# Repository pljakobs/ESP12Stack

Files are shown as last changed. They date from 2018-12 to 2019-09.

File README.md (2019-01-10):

# ESP12Stack
### An ESP12 Platform, adhering to the 30x30mm breakout boards often found but much more functional.
I have tested it with:
- ESPEasy
- SONOFF-TASMOTA
- Micropython
- Arduino
### Hardware
At this point, there is the base board which has:
- an ESP12 with all GPIO Pins brought to 2.54mm pin headers along the edge
- four WS2812B RGB or SK6812 RGBW individually addressable LEDs, which can be configured to be driven by various GPIO pins using 470Ohm resistors:
  - J02 -> GPIO2
  - J04 -> GPIO4
  - J05 -> GPIO5
  - J12 -> GPIO12
  - J13 -> GPIO13
only one of those should be installed at any given time
- low drop 3.3V regulator, the system can be powered either via the on-board USB connector or the 5V Vcc pin. Since there's no protection and those two 5V supplies form just one net, I suggest never to use both at the same time to avoid damage to your USB power source
- miniature switches for GPIO0 (FLASH) and RESET
- all necessary pull up / pull down resistors to be working as a stand alone device

In the FTDI vesion (currently untested) I have added an FTDI232 chip which should make the whole device in-place programmable, so no external USB-UART adapter is needed. Just plug it in to your PCs USB and you can talk to the ESP's UART
### There are a few other boards as well
- a 12-36V Switching Power Supply board that provides 5V (provided the feedback resistors are set correctly) to power the stack in an environment that requires those power levels (like a car)
- a five channel MOSFET board that can drive common anode LED strips
- an "experimentation" board that only has the VCC and GND pins pulled out to the outer row of mounting holes and otherwise offers as much of a "standard" layout board as possible for your own devices
### What I'm, working on:
the next board to come should be a display that just plugs on top of the base board, offering 240x240px through I2C

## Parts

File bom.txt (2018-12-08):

Partlist

Exported from esp12Stack.brd at 07.12.2018 13:59

EAGLE Version 7.7.0 Copyright (c) 1988-2016 CadSoft

Assembly variant: 

Part     Value             Package        Library       Position (inch)       Orientation

C1       100u              C0805          eagle-ltspice (0.45 0.4125)         MR270
C2       10u               C0805          eagle-ltspice (0.45 0.5875)         MR90
FLASH    SPST.B3U-3000P(M) B3U-3000P(M)   omron         (1 0.05)              MR180
GND      MCP1700SOT23      SOT-23         MCP1700       (0.6 0.45)            MR90
J02      470               R0805          eagle-ltspice (1.01875 0.525)       MR180
J04      470               R0805          eagle-ltspice (1.01875 0.61875)     MR180
J05      470               R0805          eagle-ltspice (1.01875 0.7125)      MR180
J12      470               R0805          eagle-ltspice (0.3 0.65)            MR270
J13      470               R0805          eagle-ltspice (0.3 0.4125)          MR270
JVCC     0R                R0805          eagle-ltspice (0.66875 0.51875)     MR180
LED1     WS2812B5050       WS2812B        adafruit      (1.1 1.05)            R180
LED2     WS2812B5050       WS2812B        adafruit      (0.15 1.05)           R180
LED3     WS2812B5050       WS2812B        adafruit      (0.2625 0.1125)       R0
LED4     WS2812B5050       WS2812B        adafruit      (0.975 0.1125)        R0
MDL1                       ESP8266-ESP12E ESP12E        (0.3 0.25)            R0
R1       10k               R0805          eagle-ltspice (0.5 0.85)            MR180
R2       10k               R0805          eagle-ltspice (0.5 0.75)            MR180
R3       10k               R0805          eagle-ltspice (0.66875 0.60625)     MR0
R4       10k               R0805          eagle-ltspice (0.66875 0.69375)     MR0
R5       10k               R0805          eagle-ltspice (0.75 0.35)           MR90
REST     SPST.B3U-3000P(M) B3U-3000P(M)   omron         (0.25 0.05)           MR180
SV1                        MA08-1         con-lstb      (0.0625 0.5)          R270
SV2                        MA08-1         con-lstb      (1.175 0.5)           R270
U$2      MICRO-USB         MICRO-USB      microusb (1)  (0.6 0)               MR0

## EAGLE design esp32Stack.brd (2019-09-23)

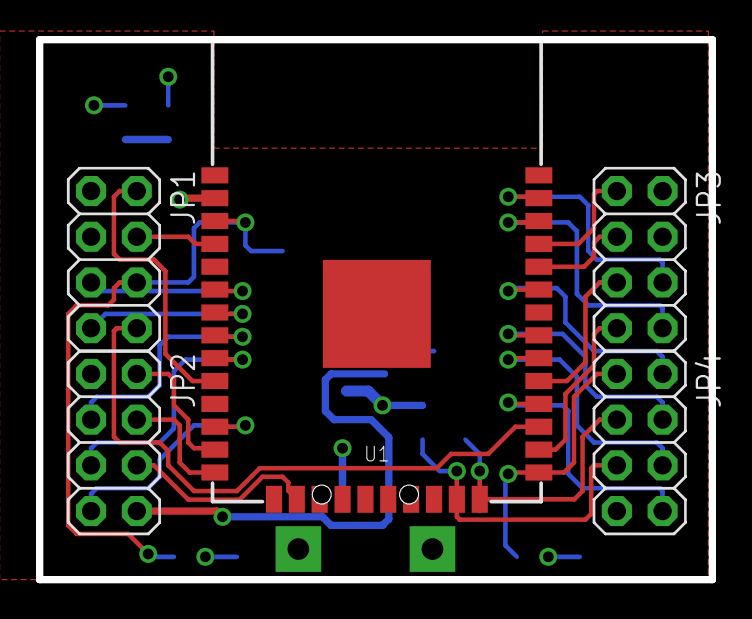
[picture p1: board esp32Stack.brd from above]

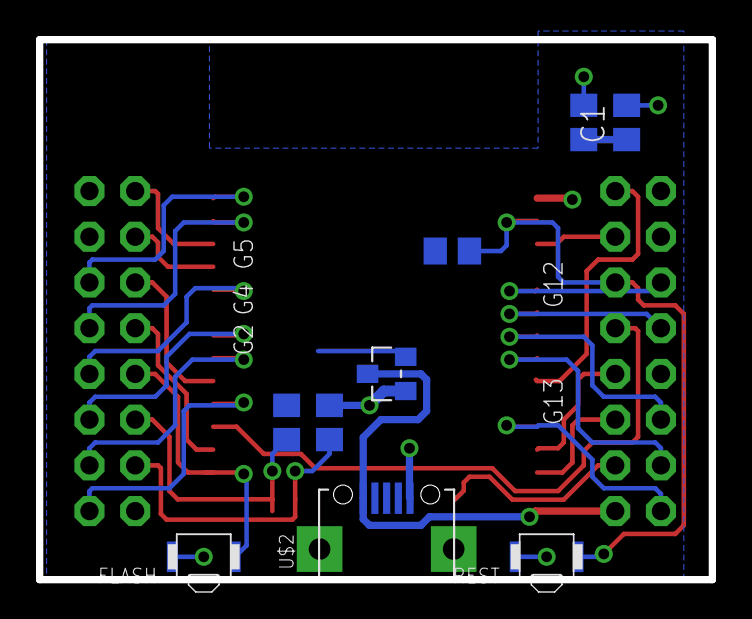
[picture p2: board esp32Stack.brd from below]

Board: 2 copper layers, 37.4 x 30.0 mm, 14 parts (9 on the bottom side), 28 nets.

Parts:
C1: 100u; C0805
C2: 10u; C0805
FLASH: SPST.B3U-3000P(M); B3U-3000P(M)
GND: MCP1700SOT23; SOT-23
JP1, JP2, JP3, JP4: 2X04
R2, R3, R5: 10k; R0805
REST: SPST.B3U-3000P(M); B3U-3000P(M)
U1: ESP-WROOM-03
U$2: MICRO-USB

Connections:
3V3: C1.1, C2.1, GND.2, R2.2, R3.2, U1.2
+5V: GND.3, JP2.8, U$2.1
ADC: JP1.4, U1.4
EN: JP1.6, R2.1, REST.1, U1.3
GND: C1.2, C2.2, FLASH.2, GND.1, JP4.7, R5.1, REST.2, U1.1, U1.5, U1.15, U1.38, U1.GND, U$2.5, U$2.GND1, U$2.GND2
GPIO0: FLASH.1, JP4.1, U1.25
GPIO2: JP4.3, R3.1, U1.24
GPIO4: JP3.7, U1.26
GPIO5: JP3.5, U1.29
GPIO12: JP2.4, U1.14
GPIO13: JP2.6, U1.16
GPIO14: JP2.2, U1.13
GPIO15: JP4.5, R5.2, U1.23
GPIO16: JP1.8, U1.27
GPIO17: JP4.8, U1.28
GPIO18: JP4.6, U1.30
GPIO19: JP4.4, U1.31
GPIO21: JP4.2, U1.33
GPIO22: JP3.8, U1.36
GPIO23: JP3.6, U1.37
GPIO25: JP1.2, U1.10
GPIO27: JP2.7, U1.12
GPIO32: JP2.3, U1.8
GPIO33: JP2.5, U1.9
GPIO34: JP1.5, U1.6
GPIO35: JP1.7, U1.7
RXD: JP3.3, U1.34
TXD: JP3.1, U1.35

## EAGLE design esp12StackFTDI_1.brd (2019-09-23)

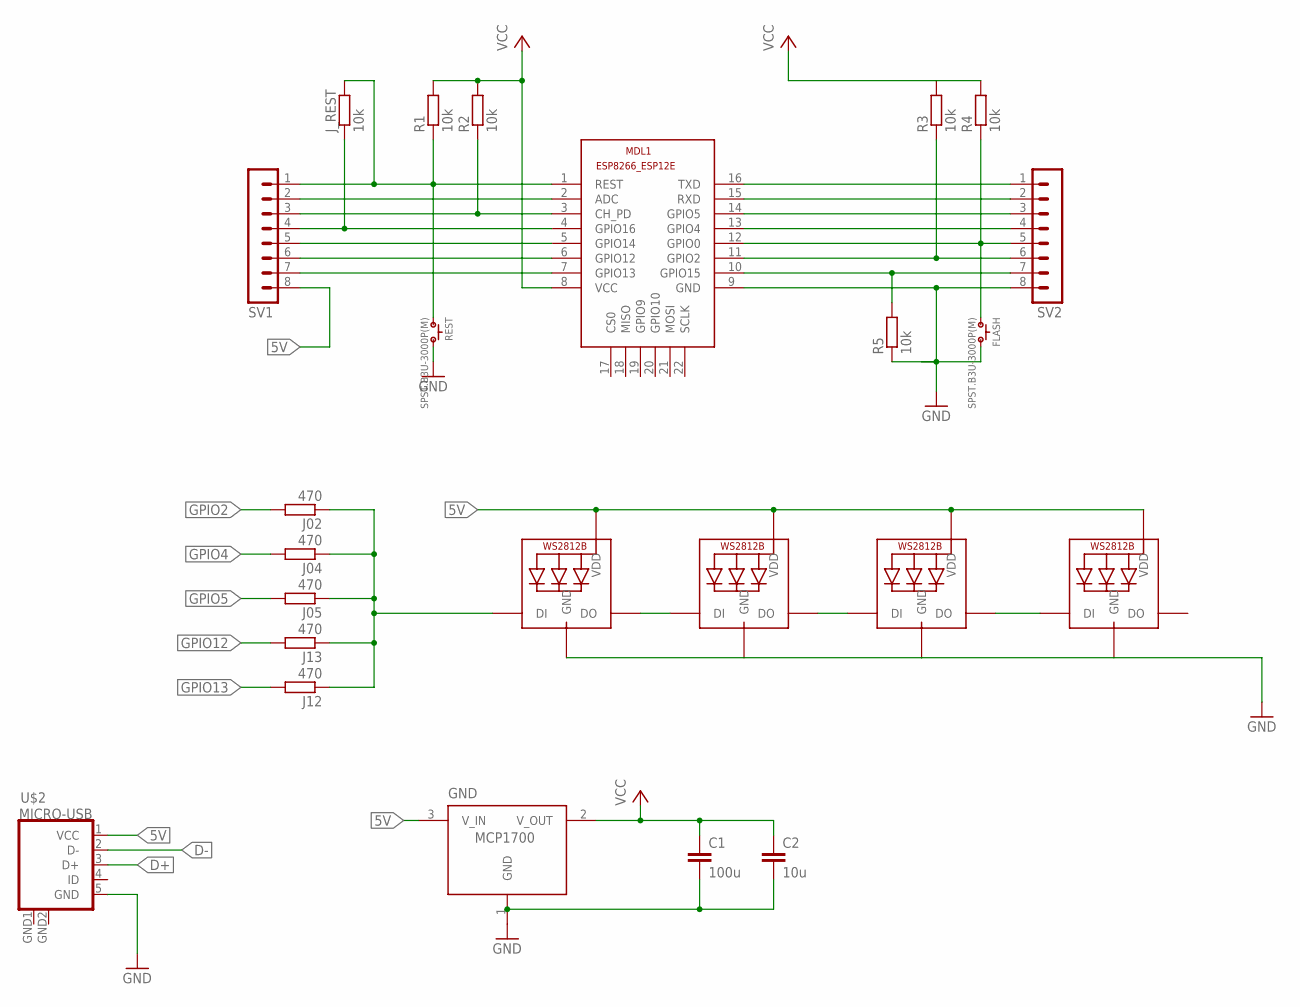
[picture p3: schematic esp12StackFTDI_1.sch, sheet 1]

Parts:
C1: 100u; C0805
C2: 10u; C0805
FLASH: SPST.B3U-3000P(M); B3U-3000P(M)
GND: MCP1700SOT23; SOT-23
J02, J04, J05, J12, J13: 470; R0603
J_REST: 10k; R0603
LED1, LED2, LED3, LED4: WS2812B5050; WS2812B
MDL1: ESP8266-12EESP8266-ESP12E; ESP8266-ESP12E
R1, R2, R3, R4, R5: 10k; R0603
REST: SPST.B3U-3000P(M); B3U-3000P(M)
SV1, SV2: MA08-1
U$2: MICRO-USB

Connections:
3V3: C1.1, C2.1, GND.2 (V_OUT), MDL1.8 (VCC), R1.2, R2.2, R3.2, R4.2; also elsewhere on the board
5V: GND.3 (V_IN), LED1.1-VDD (VDD), LED2.1-VDD (VDD), LED3.1-VDD (VDD), LED4.1-VDD (VDD), SV1.8, U$2.1 (VCC); also elsewhere on the board
ADC: MDL1.2 (ADC), SV1.2
CH_PD: MDL1.3 (CH_PD), R2.1, SV1.3
D+: U$2.3 (D+); also elsewhere on the board
D-: U$2.2 (D-); also elsewhere on the board
DIN1: J02.1, J04.1, J05.1, J12.1, J13.1, LED1.4-DIN (DI)
DOUT1DIN2: LED1.2-DOUT (DO), LED2.4-DIN (DI)
DOUT2DIN3: LED2.2-DOUT (DO), LED3.4-DIN (DI)
DOUT3DIN4: LED3.2-DOUT (DO), LED4.4-DIN (DI)
GND: C1.2, C2.2, FLASH.2, GND.1 (GND), LED1.3-GND (GND), LED2.3-GND (GND), LED3.3-GND (GND), LED4.3-GND (GND), MDL1.9 (GND), R5.1, REST.2, SV2.8, U$2.5 (GND), U$2.GND1 (GND), U$2.GND2 (GND); also elsewhere on the board
GPIO0: FLASH.1, MDL1.12 (GPIO0), R4.1, SV2.5
GPIO2: J02.2, MDL1.11 (GPIO2), R3.1, SV2.6
GPIO4: J04.2, MDL1.13 (GPIO4), SV2.4
GPIO5: J05.2, MDL1.14 (GPIO5), SV2.3
GPIO12: J13.2, MDL1.6 (GPIO12), SV1.6
GPIO13: J12.2, MDL1.7 (GPIO13), SV1.7
GPIO14: MDL1.5 (GPIO14), SV1.5
GPIO15: MDL1.10 (GPIO15), R5.2, SV2.7
GPIO16: J_REST.1, MDL1.4 (GPIO16), SV1.4
REST: J_REST.2, MDL1.1 (REST), R1.1, REST.1, SV1.1
RXD: MDL1.15 (RXD), SV2.2; also elsewhere on the board
TXD: MDL1.16 (TXD), SV2.1; also elsewhere on the board

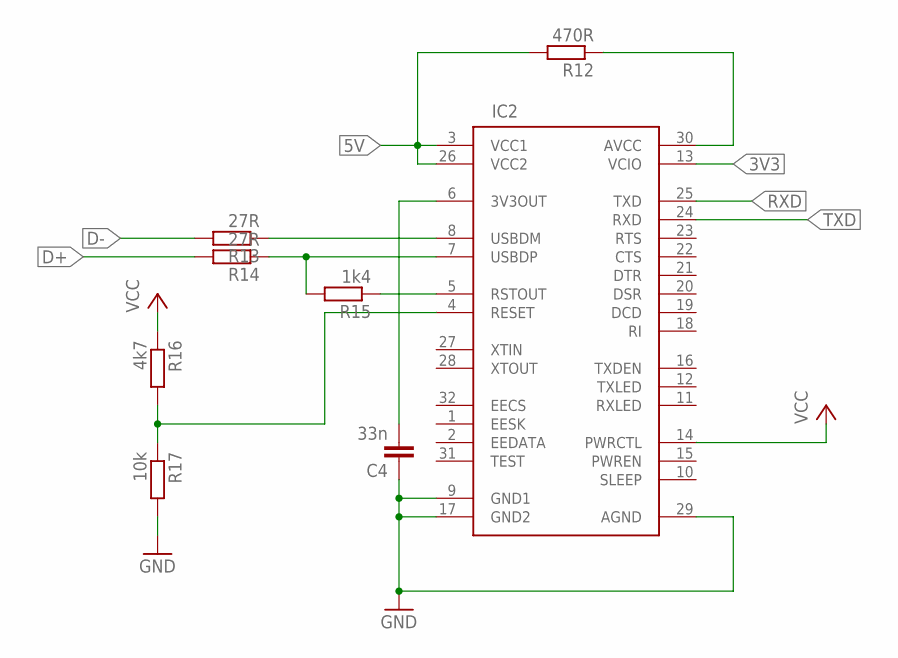
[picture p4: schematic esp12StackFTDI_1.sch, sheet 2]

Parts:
C4: 33n; C0603
IC2: FT232BM; QFP-32
R12: 470R; R0603
R13, R14: 27R; R0603
R15: 1k4; R0603
R16: 4k7; R0603
R17: 10k; R0603

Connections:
3V3: IC2.13 (VCIO), IC2.14 (PWRCTL); also elsewhere on the board
3V3OUT1: C4.2, IC2.6 (3V3OUT)
5V: IC2.3 (VCC1), IC2.26 (VCC2), R12.2, R16.1; also elsewhere on the board
AVCC1: IC2.30 (AVCC), R12.1
D+: R14.2; also elsewhere on the board
D-: R13.2; also elsewhere on the board
GND: C4.1, IC2.9 (GND1), IC2.17 (GND2), IC2.29 (AGND), R17.2; also elsewhere on the board
RESET1: IC2.4 (RESET), R16.2, R17.1
RSTOUT1: IC2.5 (RSTOUT), R15.1
RXD: IC2.25 (TXD); also elsewhere on the board
TXD: IC2.24 (RXD); also elsewhere on the board
USBDM1: IC2.8 (USBDM), R13.1
USBDP1: IC2.7 (USBDP), R14.1, R15.2

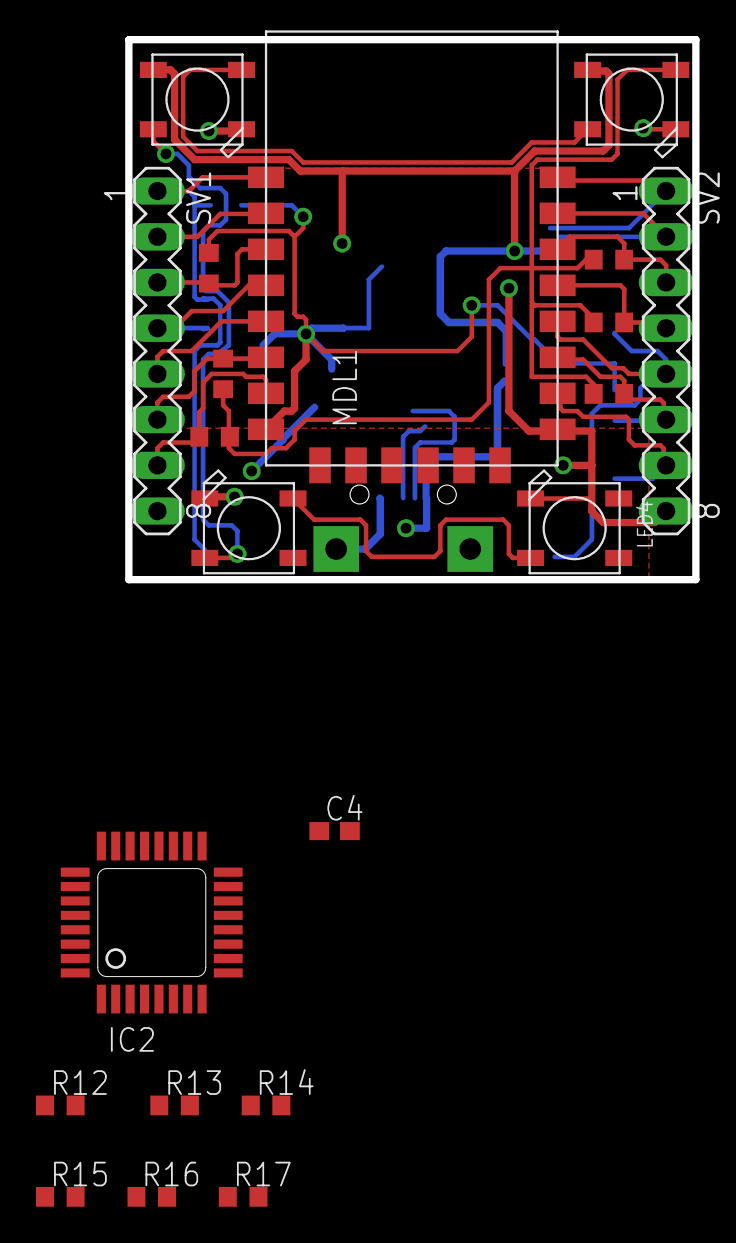
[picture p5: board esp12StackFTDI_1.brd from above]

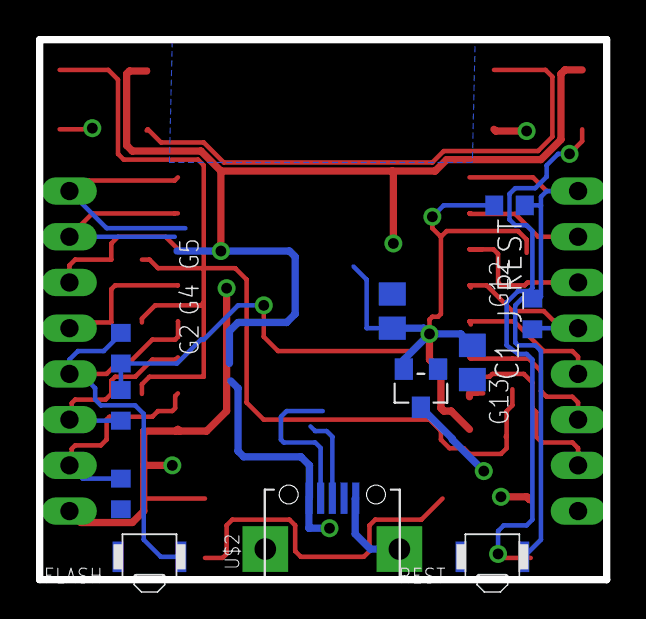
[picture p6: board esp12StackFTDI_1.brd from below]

Board: 2 copper layers, 31.5 x 30.0 mm, 32 parts (11 on the bottom side), 29 nets.

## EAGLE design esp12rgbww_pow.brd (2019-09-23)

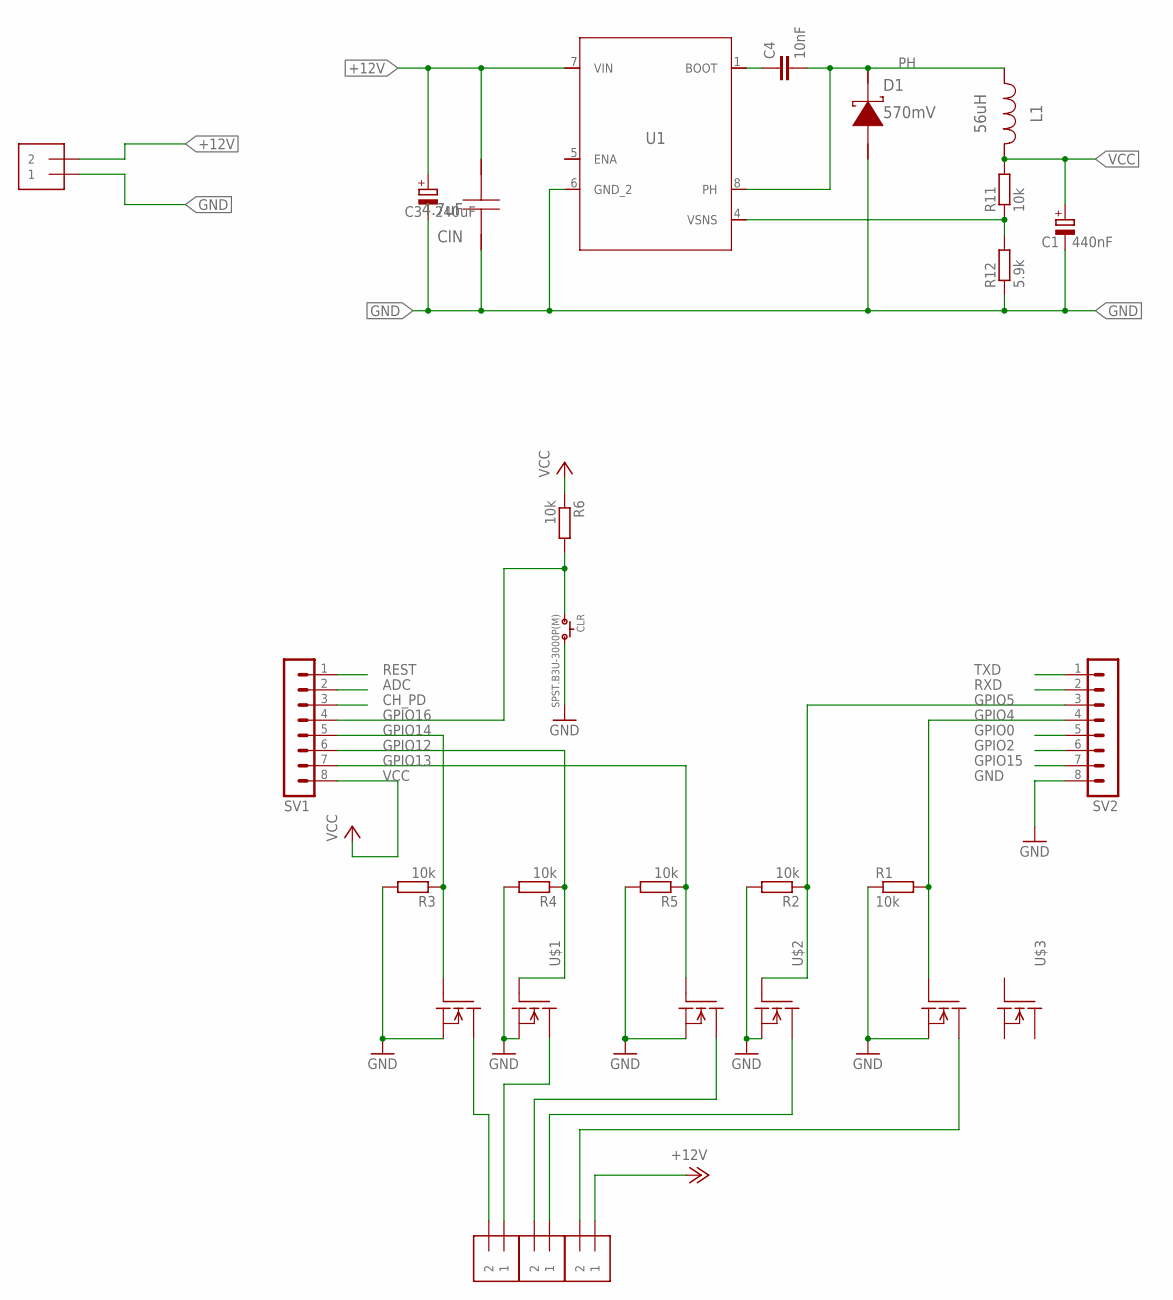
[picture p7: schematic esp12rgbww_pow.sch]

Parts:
C1: 440nF; E2,5-7
C3: 240uF; E2,5-7
C4: 10nF; C0805
CIN: 4.7uF; 1206
CLR: SPST.B3U-3000P(M); B3U-3000P(M)
D1: 570mV; SMA
J1, J2, J3, J4: 1X2-3.5MM
L1: 56uH; IND_NPI75C
R1, R2, R3, R4, R5, R6, R11: 10k; R0805
R12: 5.9k; R0805
SV1, SV2: MA08-1
U1: TPS5410DR; M08A
U$1, U$2, U$3: AOD4806; SO08

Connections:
+12V: C3.+, CIN.2, J3.1, J4.2, U1.7 (VIN)
ADC: SV1.2
B: J1.2, U$1.7 (D1), U$1.8 (D1)
BOOT: C4.1, U1.1 (BOOT)
CH_PD: SV1.3
CW: J2.1, U$2.5 (D), U$2.6 (D)
G: J1.1, U$1.5 (D), U$1.6 (D)
GND: C1.-, C3.-, CIN.1, CLR.2, D1.2 (A), J4.1, R1.1, R2.2, R3.2, R4.2, R5.2, R12.1, SV2.8, U1.6 (GND_2), U$1.1 (S1), U$1.3 (S), U$2.1 (S1), U$2.3 (S), U$3.1 (S1)
GPIO0: SV2.5
GPIO2: SV2.6
GPIO4: R1.2, SV2.4, U$3.2 (G1)
GPIO5: R2.1, SV2.3, U$2.4 (G)
GPIO12: R4.1, SV1.6, U$1.4 (G)
GPIO13: R5.1, SV1.7, U$2.2 (G1)
GPIO14: R3.1, SV1.5, U$1.2 (G1)
GPIO15: SV2.7
GPIO16: CLR.1, R6.2, SV1.4
PH: C4.2, D1.1 (K), L1.2, U1.8 (PH)
R: J2.2, U$2.7 (D1), U$2.8 (D1)
REST: SV1.1
RXD: SV2.2
SENS: R11.1, R12.2, U1.4 (VSNS)
TXD: SV2.1
VCC: C1.+, L1.1, R6.1, R11.2, SV1.8
WW: J3.2, U$3.7 (D1), U$3.8 (D1)

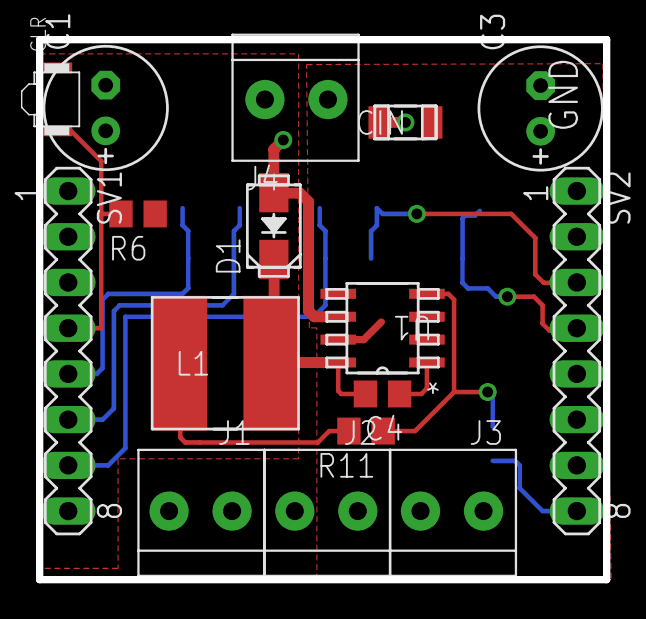
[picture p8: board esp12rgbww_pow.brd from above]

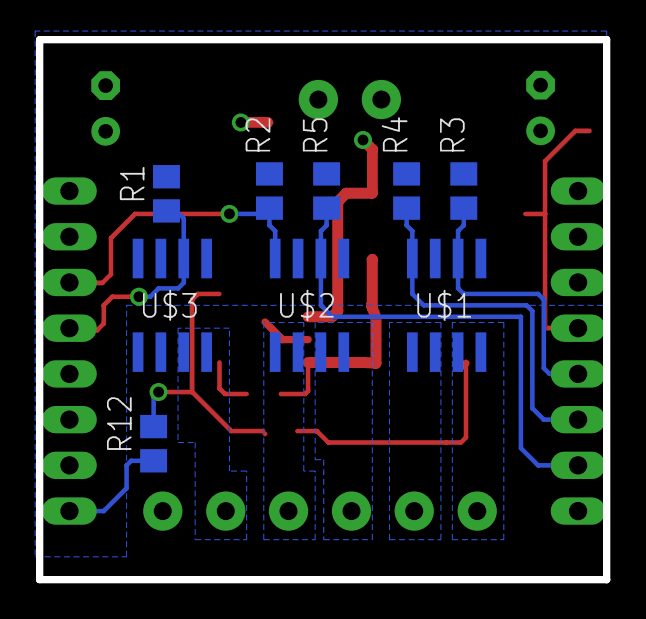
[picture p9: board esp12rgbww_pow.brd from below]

Board: 2 copper layers, 31.5 x 30.0 mm, 25 parts (9 on the bottom side), 17 nets.

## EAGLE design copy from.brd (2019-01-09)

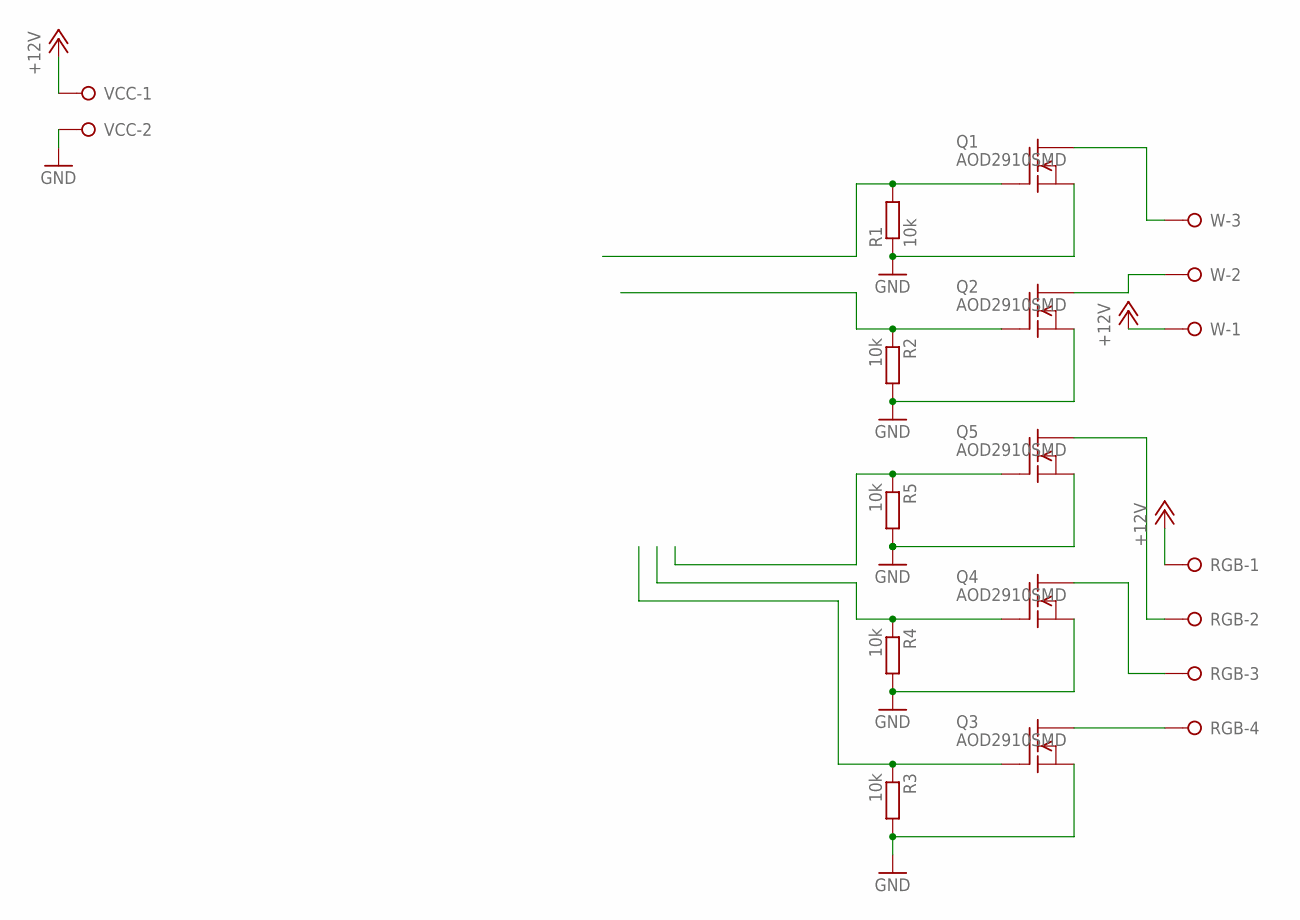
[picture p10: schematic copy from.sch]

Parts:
Q1, Q2, Q3, Q4, Q5: AOD2910SMD; DPAK-3
R1, R2, R3, R4, R5: 10k; R0805
RGB: W237-04P; W237-4P
VCC: W237-02P; W237-132
W: W237-03P; W237-133

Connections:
+12V: RGB.1, VCC.1, W.1
B: Q3.4 (D), RGB.4
CW: Q2.4 (D), W.2
G: Q4.4 (D), RGB.3
GND: Q1.3 (S), Q2.3 (S), Q3.3 (S), Q4.3 (S), Q5.3 (S), R1.1, R2.2, R3.2, R4.2, R5.2, VCC.2
R: Q5.4 (D), RGB.2
RGB-B: Q3.1 (G), R3.1
RGB-CW: Q2.1 (G), R2.1
RGB-G: Q4.1 (G), R4.1
RGB-R: Q5.1 (G), R5.1
RGB-WW: Q1.1 (G), R1.2
WW: Q1.4 (D), W.3

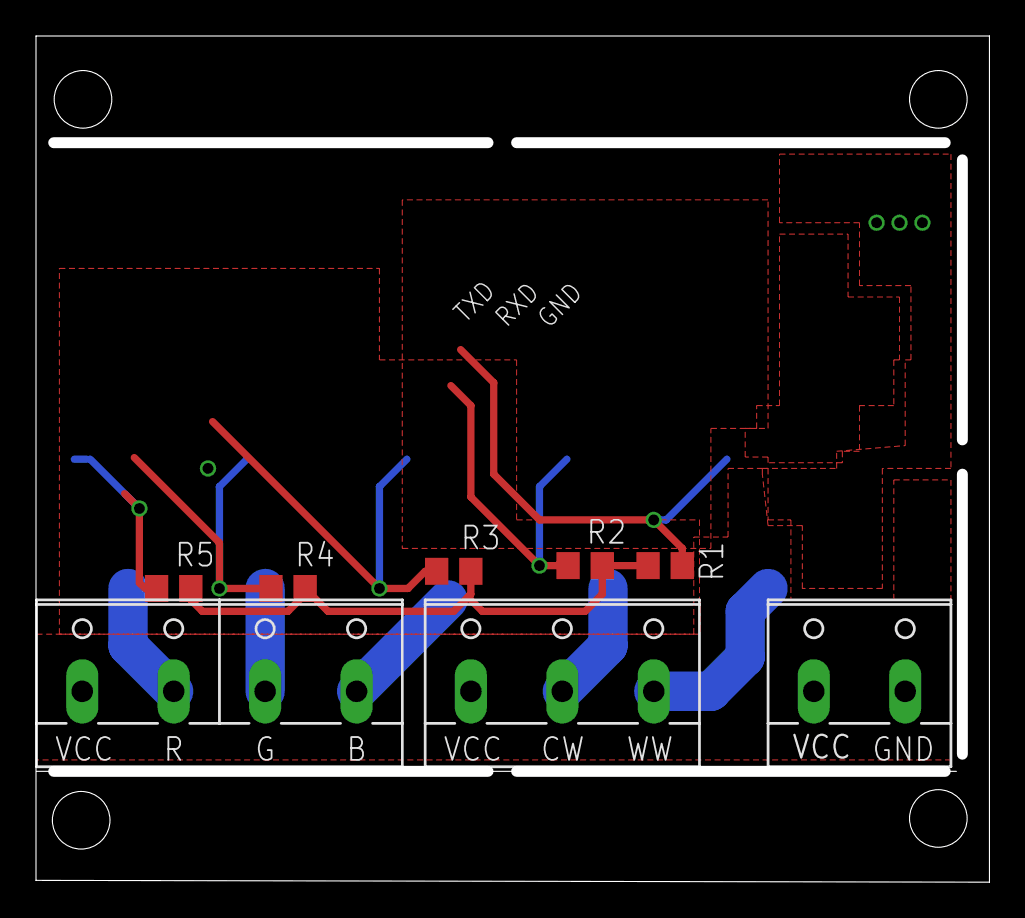
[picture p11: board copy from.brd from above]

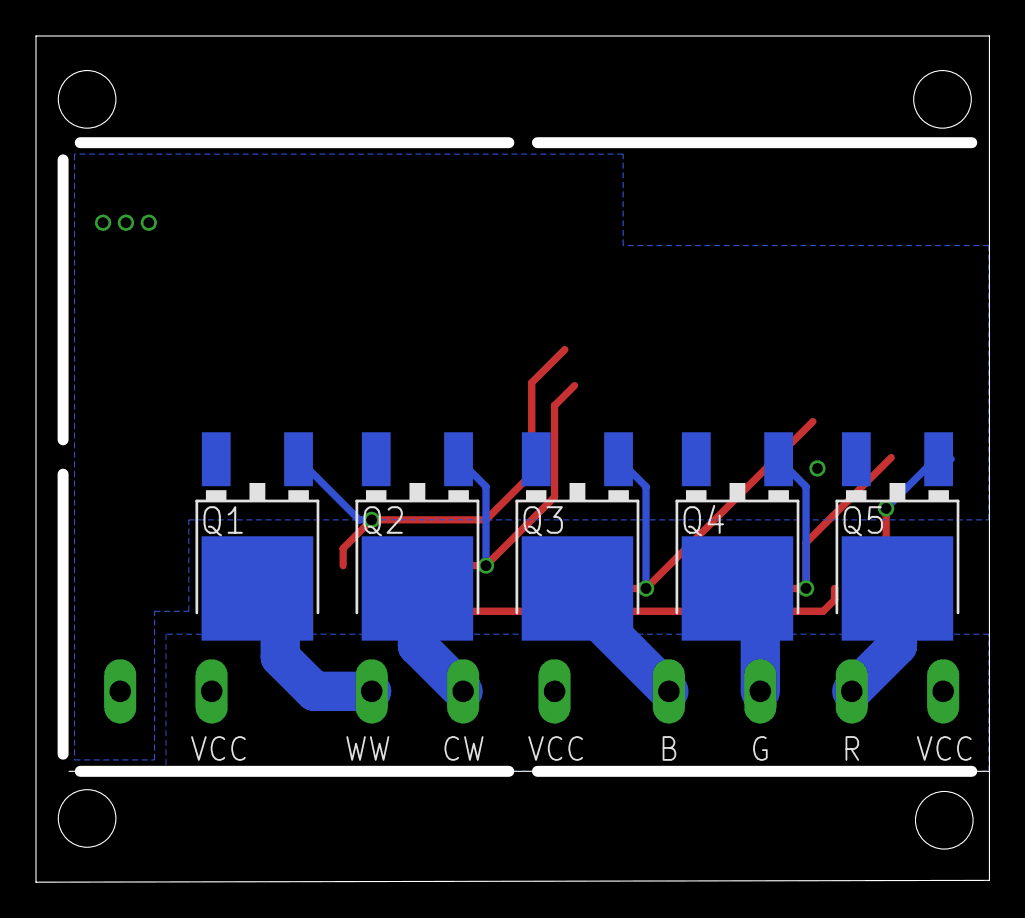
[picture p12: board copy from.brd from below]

Board: 2 copper layers, 53.0 x 47.0 mm, 13 parts (5 on the bottom side), 12 nets.

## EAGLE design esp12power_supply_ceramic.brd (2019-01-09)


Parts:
C1: 2.7nF; C0805K
C2: 56nF; C0805K
C3, C6: 45µ; C1210K
C4: 10nF; C0805
C5: 150pF; C0805K
CIN: 4.7uF; 1206
D1: 570mV; SMA
JP1: PINHD-2X2; 2X02
L1: 68uH; IND_NPI75C
R1: 1.78k; R0805
R11: 10k; R0805
R12: 3.24k; R0805
SV1, SV2: MA08-1
U1: TPS5410DR; M08A
VCC: W237-02P; W237-132

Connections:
+3V3: C1.1, C3.1, C6.1, L1.1, R11.2, SV1.8
+12V: CIN.2, JP1.1, JP1.3, U1.7 (VIN), VCC.1
BOOT: C4.1, U1.1 (BOOT)
GND: C2.2, C3.2, C5.2, C6.2, CIN.1, D1.2 (A), JP1.2, JP1.4, R12.1, SV2.8, U1.6 (GND_2), VCC.2
unnamed: C2.1, R1.1
PH: C4.2, D1.1 (K), L1.2, U1.8 (PH)
VSNS: C1.2, C5.1, R1.2, R11.1, R12.2, U1.4 (VSNS)


Board: 2 copper layers, 31.5 x 30.0 mm, 17 parts (1 on the bottom side), 7 nets.

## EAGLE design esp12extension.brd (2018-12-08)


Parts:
PAD1, PAD2, PAD3, PAD4, PAD5, PAD6, PAD7, PAD8, PAD9, PAD10, PAD11, PAD12, PAD13, PAD14, PAD15, PAD16, PAD17, PAD18, PAD19, PAD20, PAD21, PAD22, PAD23, PAD24, PAD25, PAD26, PAD27, PAD28, PAD29, PAD30, PAD31, PAD32, PAD33, PAD34, PAD35, PAD36, PAD37, PAD38, PAD39, PAD40, PAD41, PAD42, PAD43, PAD44, PAD45, PAD46, PAD47, PAD48, PAD49, PAD50, PAD51, PAD52, PAD53, PAD54, PAD55, PAD56, PAD57, PAD58, PAD59, PAD60, PAD61, PAD62, PAD63, PAD64, PAD65, PAD66, PAD67, PAD68, PAD69, PAD70, PAD71, PAD72, PAD73, PAD74, PAD75, PAD76, PAD77, PAD78, PAD79, PAD80, PAD81, PAD82, PAD83, PAD84, PAD85, PAD86, PAD87, PAD88, PAD89, PAD90, PAD91, PAD92, PAD93, PAD94, PAD95, PAD96, PAD97, PAD98, PAD99, PAD100, PAD101, PAD102, PAD103: 1,6/0,8
SV1, SV2: MA08-1

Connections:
GND: PAD11.1, PAD22.1, PAD31.1, PAD40.1, PAD49.1, PAD58.1, PAD67.1, PAD76.1, PAD85.1, PAD94.1, PAD103.1, SV2.8
VCC: PAD1.1, PAD12.1, PAD23.1, PAD32.1, PAD41.1, PAD50.1, PAD59.1, PAD68.1, PAD77.1, PAD86.1, PAD95.1, SV1.8


Board: 2 copper layers, 31.5 x 30.0 mm, 105 parts (0 on the bottom side), 2 nets.

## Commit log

2018-12-08 created shields for Power Supply, five channel Mosfet (max 20V7.5A) and general experimentation
    [esp12Stack.GBL, esp12Stack.GBO, esp12Stack.GBP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]
2018-12-08 added Gerber/Excellon files
    [esp12Stack.GBL, esp12Stack.GBO, esp12Stack.GBP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]
2019-01-09 added an ftdi version
    [copy from.brd, copy from.sch, esp12StackFTDI.brd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]
2019-01-10 minor routing changes
    [esp12StackFTDI.brd]
2019-01-10 Deep Sleep capability
    added a jumper Position to connect GIPO16 and REST to enable wake up from deep sleep.
    [esp12Stack.brd, esp12Stack.sch, esp12StackFTDI.brd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]
2019-09-23 FT232 module
    FT232 Module now functional as a prototype
    [esp12StackFTDI.sch, esp12StackFTDI_1.brd, esp12StackFTDI_1.sch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]

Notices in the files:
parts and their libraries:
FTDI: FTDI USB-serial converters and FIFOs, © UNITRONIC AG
